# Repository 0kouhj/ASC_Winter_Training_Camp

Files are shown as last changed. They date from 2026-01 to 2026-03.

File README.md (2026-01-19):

# ASC_Winter_Training_Camp
## 项目成员
邓涵天 王泽源
## 仓库文件结构
- docs/ : 存放项目相关文档与图文资料
- Firmware/ : 放置单片机项目工程代码
- Hardware/ : 放置电路原理图及 PCB 源文件
- Mechanical/ : 放置各类机械结构 3D 模型文件 (STL/STEP)
## 项目代码结构 (Firmware)
- 工程基础文件 : 芯片启动文件及HAL库
- App/ : 应用层，用于存放控制算法（如 PID、滤波等）
- Bsp/ : 板级支持包，负责底层外设驱动（如 电机、传感器驱动）
- Config/ : 配置文件，存放系统参数设置与小车物理数据
## PCB丝印
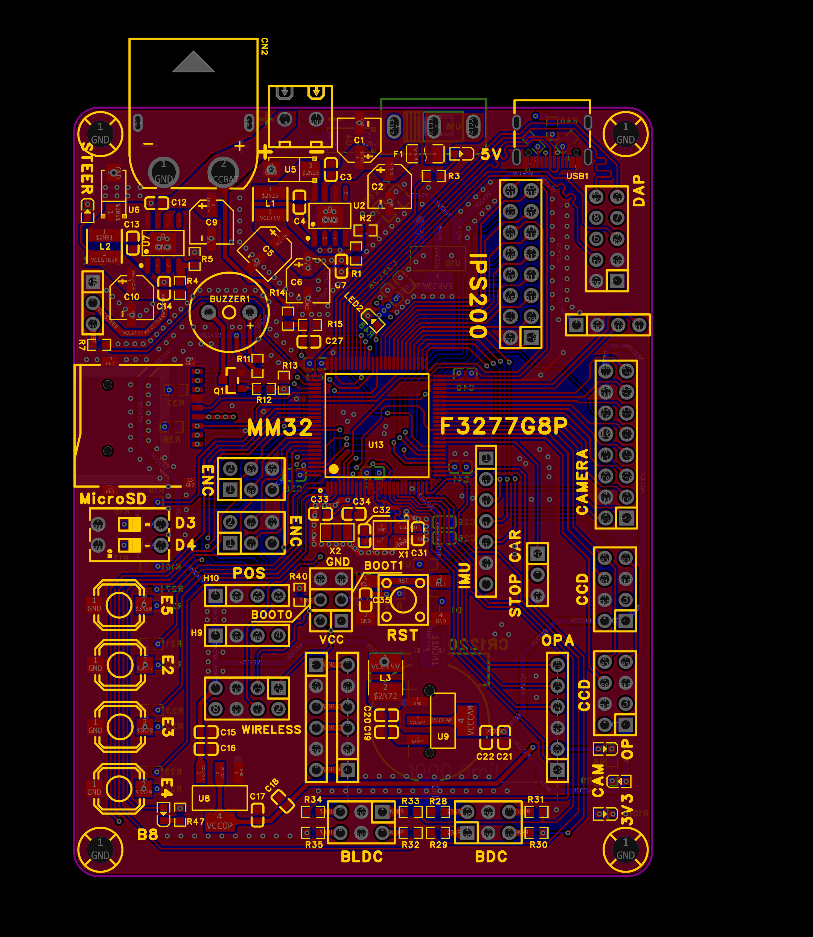
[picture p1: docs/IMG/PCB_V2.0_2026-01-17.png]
PCB_V2.0

## 硬件选型
1. 电机:MG513(GMR) 12V 1:30
2. 68mm硅胶轮胎
3. ICM42688姿态传感器

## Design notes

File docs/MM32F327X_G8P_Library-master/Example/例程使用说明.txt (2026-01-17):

例程的主要作用只是告诉大家如何使用各种库函数
因此例程内的库文件不一定是最新的，当通过库例程学习完之后
请使用 Seekfree_xxx_Opensource_Library 开源库进行开发。

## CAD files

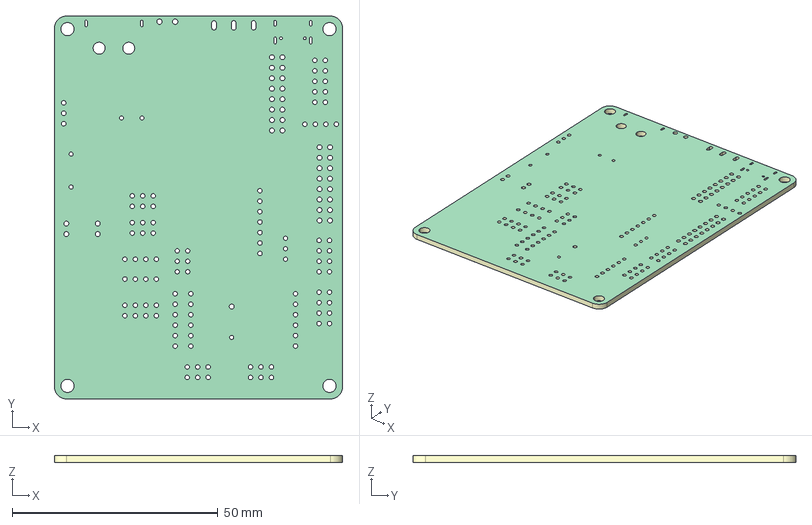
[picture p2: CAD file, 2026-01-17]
Mechanical/PCB_3D_V2.0_2026-01-17.step
70.0 x 93.0 x 1.59 mm
Board~gg4W
TopCopper~gg4W
BottomCopper~gg4W
TopFpcStiffener~gg4W
BottomFpcStiffener~gg4W

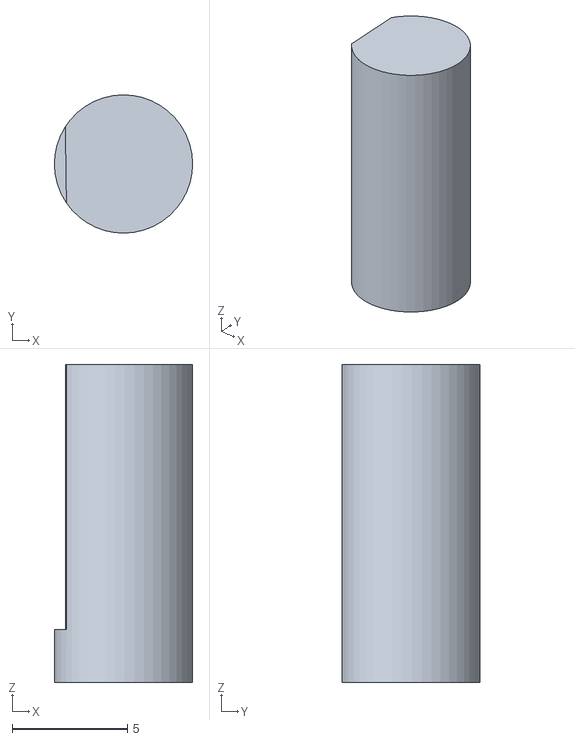
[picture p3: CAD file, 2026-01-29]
Mechanical/v2.0/STL打印文件/小车 - 电机轴.stp-1.STL
6.00 x 6.00 x 13.8

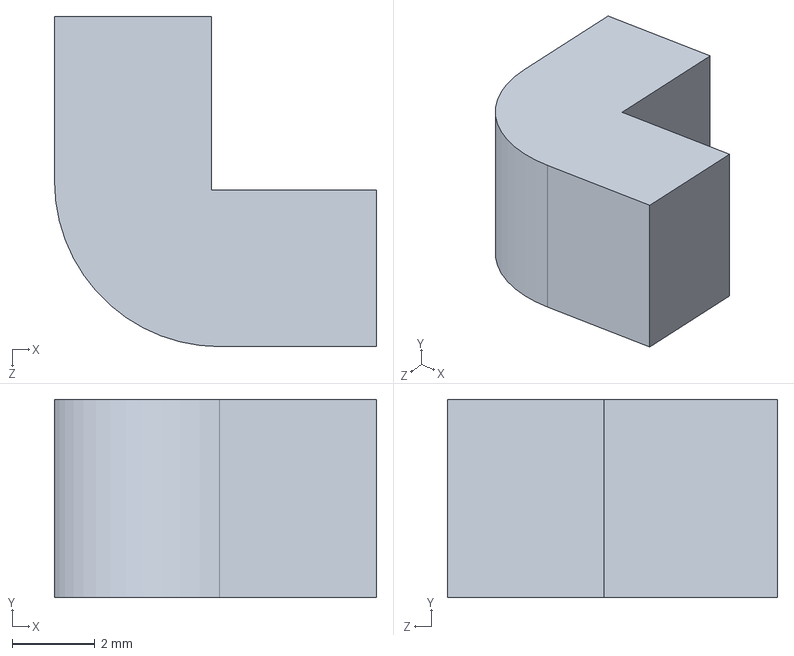
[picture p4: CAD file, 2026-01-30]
Mechanical/v2.0/插销.SLDPRT
7.80 x 4.80 x 8.00 mm

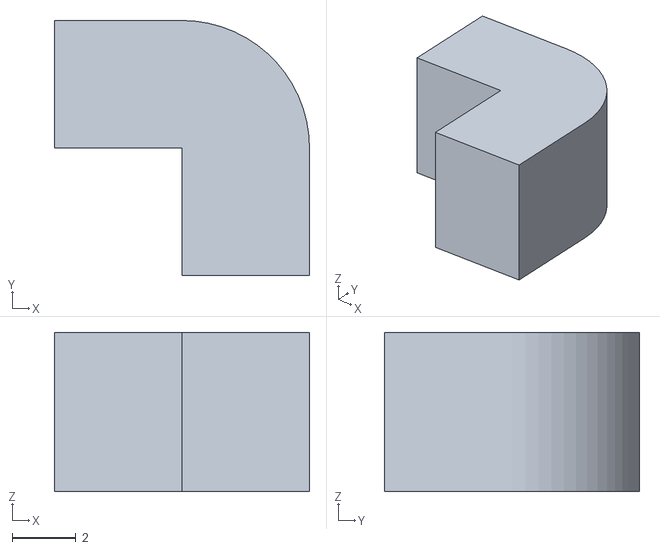
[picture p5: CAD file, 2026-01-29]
Mechanical/v2.0/STL打印文件/小车 - 插销-2.STL
8.00 x 8.00 x 5.00

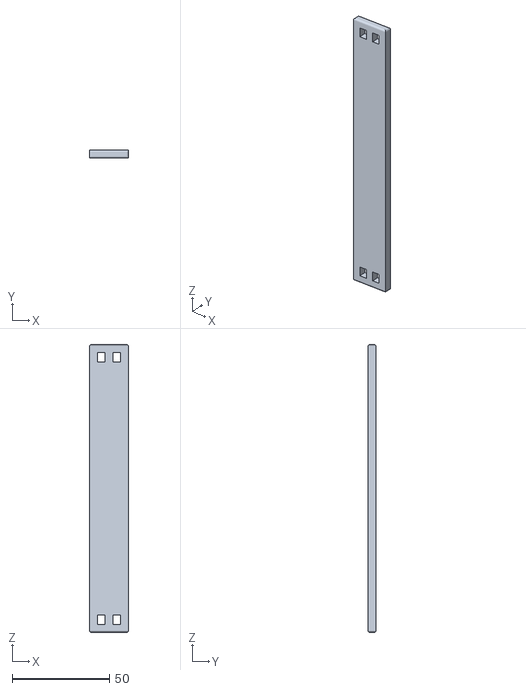
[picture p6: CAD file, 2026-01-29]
Mechanical/v2.0/STL打印文件/小车 - 电机下固定板-1.STL
20.0 x 4.00 x 148.0

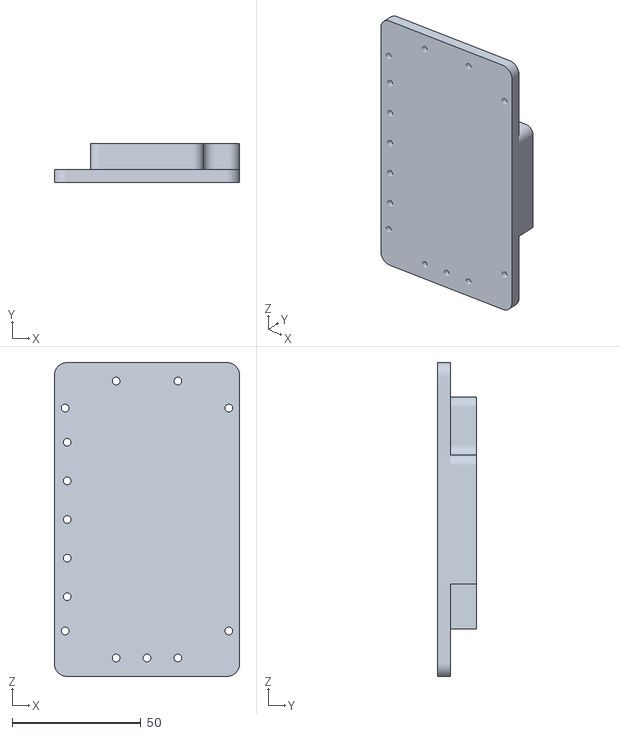
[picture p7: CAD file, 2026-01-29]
Mechanical/v2.0/STL打印文件/小车 - 底板-2.STL
72.0 x 15.0 x 122.0

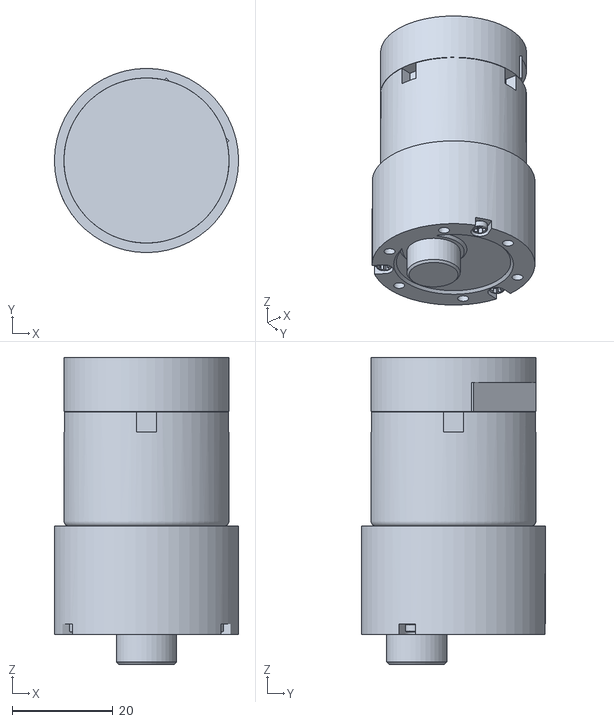
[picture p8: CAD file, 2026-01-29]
Mechanical/v2.0/STL打印文件/小车 - 电机后半部分.stp-2.STL
36.6 x 36.6 x 61.0

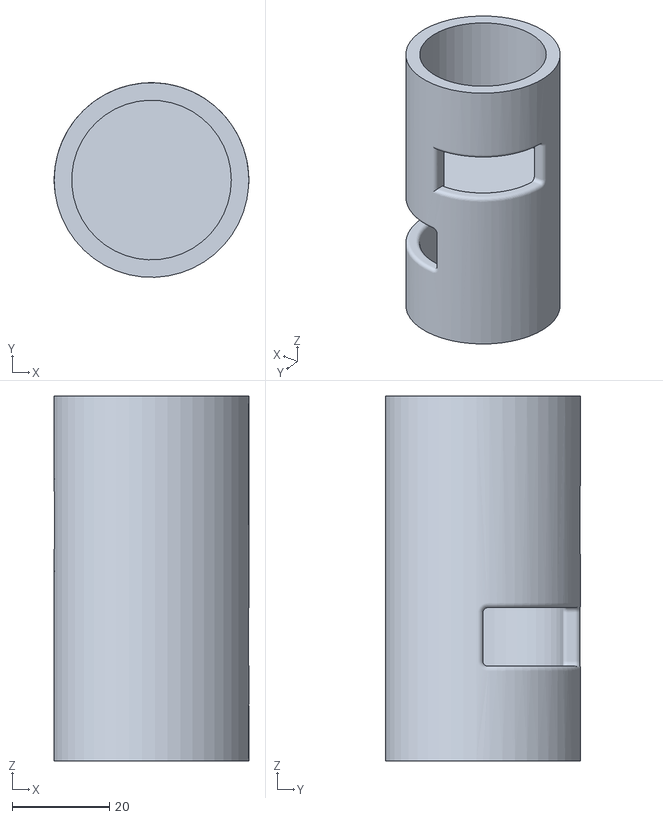
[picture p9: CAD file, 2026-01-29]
Mechanical/v2.0/STL打印文件/小车 - 电机套筒-1.STL
40.0 x 40.0 x 75.0

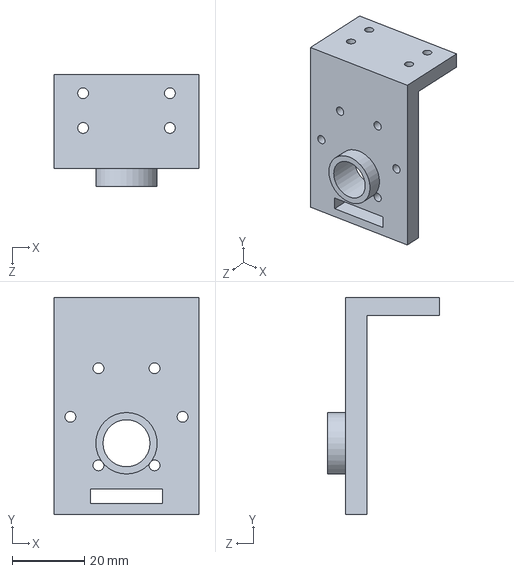
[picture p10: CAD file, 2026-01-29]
Mechanical/v2.0/电机固定件.SLDPRT
40.0 x 60.0 x 31.0 mm

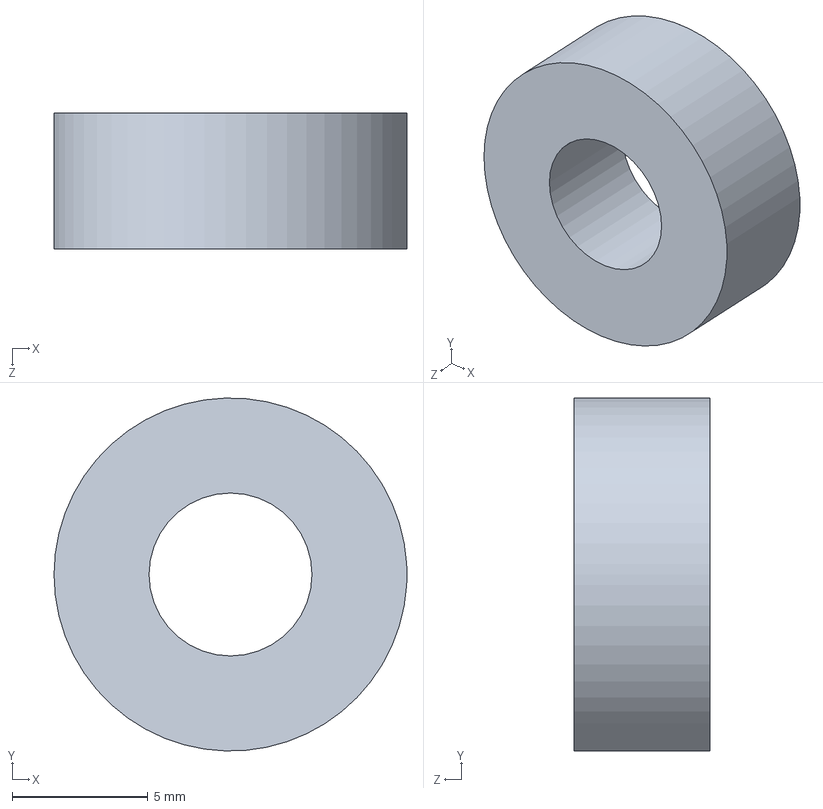
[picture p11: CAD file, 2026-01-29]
Mechanical/v2.0/轴承.SLDPRT
13.0 x 13.0 x 5.00 mm

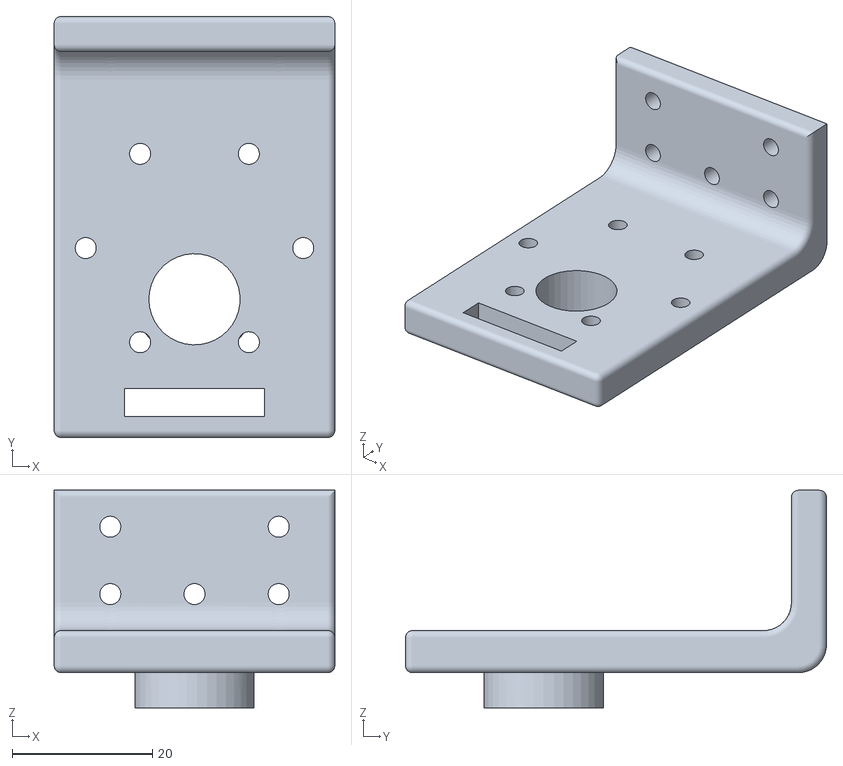
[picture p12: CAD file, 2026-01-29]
Mechanical/v2.0/STL打印文件/小车 - 电机固定件-2.STL
40.0 x 60.0 x 31.0

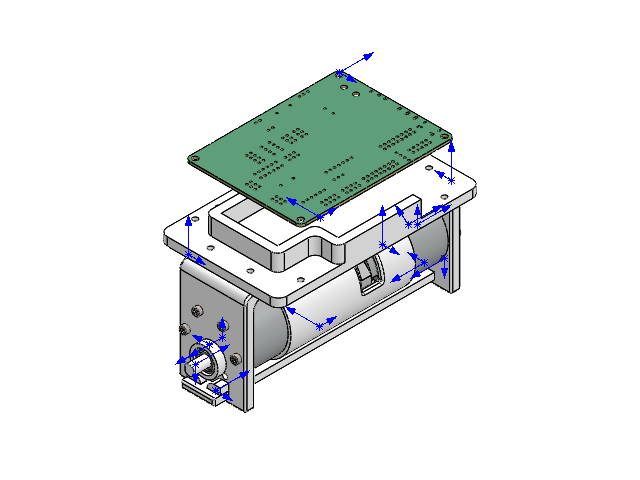
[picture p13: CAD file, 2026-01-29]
Mechanical/v2.0/小车.SLDASM
电机套筒
电机后半部分.stp x 2
电机轴.stp x 2
电机固定件 x 2
deep groove ball bearings gb x 2
hexagon socket head cap screws gb x 9
电机下固定板
插销 x 4
底板
Board~gg4W.step

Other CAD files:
Mechanical/v2.0/插销.gcode.3mf
Mechanical/v2.0/电机轴.stp.SLDPRT
Mechanical/v2.0/底座.SLDPRT
Mechanical/v2.0/11组v2.0小车.gcode.3mf
Mechanical/v2.0/STL打印文件/小车 - 电机轴.stp-2.STL
Mechanical/v2.0/STL打印文件/小车 - 插销-5.STL
Mechanical/v1.0/上底盘.SLDPRT
Mechanical/v1.0/下底盘.SLDPRT
Mechanical/v1.0/固定件-电机+下底盘.SLDPRT
Mechanical/v1.0/固定件-电机+电机.SLDPRT
Mechanical/v1.0/固定件.SLDPRT
Mechanical/v2.0/STL打印文件/小车 - 插销-1.3mf
Mechanical/v2.0/STL打印文件/小车 - 插销-1.STL
Mechanical/v2.0/STL打印文件/小车 - 插销-3.STL
Mechanical/v2.0/STL打印文件/小车 - 电机后半部分.stp-1.STL
Mechanical/v2.0/STL打印文件/小车 - 电机固定件-1.STL
Mechanical/v2.0/底板.SLDPRT
Mechanical/v2.0/插销.STL
Mechanical/v2.0/电机下固定板.SLDPRT
Mechanical/v2.0/电机后半部分.stp
Mechanical/v2.0/电机后半部分.stp.SLDPRT
Mechanical/v2.0/电机套筒.SLDPRT
Mechanical/v2.0/电机轴.stp

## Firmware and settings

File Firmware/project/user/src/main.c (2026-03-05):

/*********************************************************************************************************************
 * MM32F327X-G8P Opensourec Library 即（MM32F327X-G8P 开源库）是一个基于官方 SDK 接口的第三方开源库
 * Copyright (c) 2022 SEEKFREE 逐飞科技
 *
 * 本文件是 MM32F327X-G8P 开源库的一部分
 *
 * MM32F327X-G8P 开源库 是免费软件
 * 您可以根据自由软件基金会发布的 GPL（GNU General Public License，即 GNU通用公共许可证）的条款
 * 即 GPL 的第3版（即 GPL3.0）或（您选择的）任何后来的版本，重新发布和/或修改它
 *
 * 本开源库的发布是希望它能发挥作用，但并未对其作任何的保证
 * 甚至没有隐含的适销性或适合特定用途的保证
 * 更多细节请参见 GPL
 *
 * 您应该在收到本开源库的同时收到一份 GPL 的副本
 * 如果没有，请参阅<https://www.gnu.org/licenses/>
 *
 * 额外注明：
 * 本开源库使用 GPL3.0 开源许可证协议 以上许可申明为译文版本
 * 许可申明英文版在 libraries/doc 文件夹下的 GPL3_permission_statement.txt 文件中
 * 许可证副本在 libraries 文件夹下 即该文件夹下的 LICENSE 文件
 * 欢迎各位使用并传播本程序 但修改内容时必须保留逐飞科技的版权声明（即本声明）
 *
 * 文件名称          main
 * 公司名称          成都逐飞科技有限公司
 * 版本信息          查看 libraries/doc 文件夹内 version 文件 版本说明
 * 开发环境          IAR 8.32.4 or MDK 5.37
 * 适用平台          MM32F327X_G8P
 * 店铺链接          https://seekfree.taobao.com/
 *
 * 修改记录
 * 日期              作者                备注
 * 2022-08-10        Teternal            first version
 ********************************************************************************************************************/

#include "zf_common_headfile.h"
#include "zf_common_debug.h"
// 打开新的工程或者工程移动了位置务必执行以下操作
// 第一步 关闭上面所有打开的文件
// 第二步 project->clean  等待下方进度条走完

// 本例程是开源库移植用空工程

// **************************** 代码区域 ****************************
// *************************用户自定义包含****************************
#include "bsp_led.h"
#include "bsp_buzzer.h"
#include "bsp_oled.h"
#include "bsp_imu.h"
#include "bsp_motor.h"
#include "bsp_encoder.h"
#include "bsp_battery.h"
#include "bsp_bluetooth.h"

#include "kalman.h"

#include "Menu.h"
#include "Control.h"

#include "test.h"
#include "param_config.h"
#include "Simple_Timewheel.h"
// *************************用户自定义包含****************************

// 函数声明
static void OLED_Start(void);
// 函数声明

// DEBUG
char line_str[] = "*  DEBUG MODE ON  *\r\n";
// DEBUG

// Timewheel
extern volatile uint8_t tick_flag; // 时间轮滴答标志
extern volatile uint8_t tick_flag_2;
// Timewheel
int main(void)
{
    clock_init(SYSTEM_CLOCK_120M); // 初始化芯片时钟 工作频率为 120MHz
    debug_init();                  // 初始化默认 Debug UART

    // TIM 与 Encoder
    pit_ms_init(TIME_TIM, 1); // 使用TIM6进行按键扫描
    interrupt_set_priority(TIME_PRIORITY, 0);

    pit_ms_init(IMU_TIM, 1);
    interrupt_set_priority(IMU_PRIORITY, 1);
    // TIM 与 Encoder

    // 数据初始化
    Param_Init();
    // 数据初始化

    // 电机
    motor_init();
    encoder_init();
    // 电机

    // 此处编写用户代码 例如外设初始化代码等
    key_init(10);
    LED_Init();
    Buzzer_Init();
    battery_init();
    OLED_Init();
    Menu_Init();
    Attitude_Init();
    bluetooth_init();

    // 此处编写用户代码 例如外设初始化代码等

    // 自检
    LED_On(ALL);
    // Buzzer_On();
    OLED_Start();
    if (ICM42688_I2C_Init() != 0)
    {
        OLED_Clear();
        OLED_ShowString(0, 0, "IMU ERROR!", OLED_8X16);
        OLED_Update();
        system_delay_ms(1000);
    }
    else
    {
        OLED_Clear();
        OLED_ShowString(0, 0, "IMU OK!", OLED_8X16);
        OLED_Update();
        system_delay_ms(1000);
    }
    LED_Off(ALL);
    Buzzer_Off();
    // 自检

    OLED_Clear();

    add_task(1, All_Update);    // 每5ms更新所有控制相关任务
    add_task(30, Menu_Process); // 每30ms处理菜单
    // add_task(100, battery_update); // 每100ms更新电池电压
    add_task(30, key_scanner); // 每25ms按键扫描
    // add_task(10, Bluetooth_Command_Process); // 每10ms处理蓝牙命令

    sys_ready =1;

    while (1)
    {
        // Debug
        // OLED_Clear();
        // test_key();
        // Debug
        if (tick_flag)
        {
            time_wheel_run();
            tick_flag = 0;
        }
    }
}
// **************************** 代码区域 ****************************
static void OLED_Start(void)
{
    OLED_ShowString(0, 0, "---------------------", OLED_6X8);
    OLED_ShowString(0, 24, "---------------------", OLED_6X8);
    OLED_ShowString(0, 6, "->SYSTEM START<-", OLED_8X16);
    OLED_ShowString(0, 32, "Team Member:", OLED_8X16);
    OLED_ShowString(0, 48, "aaa", OLED_6X8);
    OLED_ShowString(0, 56, "bbb", OLED_6X8);
    OLED_ShowString(90, 32, "11", OLED_8X16);
    OLED_Update();
}

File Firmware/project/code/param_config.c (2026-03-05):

#include "param_config.h"
#include "Control.h"
// 实例化全局变量
SYSTEM_CONFIG_T Config;
SYSTEM_STATE_T State;
ICM42688_t Icm;
/**
 * @brief 初始化ICM42688的值
 * @note  开机时调用
 */
static void Icm42688_Init(void)
{
    // 原始数据清零
    Icm.accel_x_raw = 0;
    Icm.accel_y_raw = 0;
    Icm.accel_z_raw = 0;
    Icm.gyro_x_raw = 0;
    Icm.gyro_y_raw = 0;
    Icm.gyro_z_raw = 0;

    // 物理量清零
    Icm.accel_x_g = 0.0f;
    Icm.accel_y_g = 0.0f;
    Icm.accel_z_g = 0.0f;
    Icm.gyro_x_dps = 0.0f;
    Icm.gyro_y_dps = 0.0f;
    Icm.gyro_z_dps = 0.0f;
}

/**
 * @brief 实时状态初始化
 * @note  每次开机时调用，将所有状态清零
 */
static void State_Init(void)
{
    State.pitch = 0.0f;
    State.roll = 0.0f;
    State.yaw = 0.0f;
    State.gyro_x = 0.0f;
    State.gyro_y = 0.0f;
    State.motor_target_speed_left = 0;
    State.motor_target_speed_right = 0;
    State.motor_actual_speed_left = 0;
    State.motor_actual_speed_right = 0;
    State.is_stop = 0; // 开机默认锁定电机，保护安全
    State.run_stage = 0;
    State.loop_count = 0;
    State.menu_index = 0;
    State.battery_v = 0.0f;
    State.system_tick = 0;
}

/**
 * @brief 参数默认初始化
 * @note  当检测到Flash无数据时，加载这些默认值
 */
void Param_Init(void)
{
    State_Init();
    Icm42688_Init();

    // 1. 默认模式
    Config.boot.boot_mode = MODE_1;

    // 2. 电机环默认值
    Config.motor_l.Kp = 80.0f;
    Config.motor_l.Ki = 2.0f; // 适量积分消除稳态误差
    Config.motor_l.Kd = 0.5f;
    Config.motor_l.integral = 0.0f;
    Config.motor_l.i_max = 8000.0f; // 积分限幅，设为输出上限的一半
    Config.motor_l.err_last = 0.0f;
    Config.motor_l.out_max = MOTOR_MAX_PWM; // 必须设为 10000.0f

    Config.motor_r.Kp = 80.0f;
    Config.motor_r.Ki = 2.0f;
    Config.motor_r.Kd = 0.5f;
    Config.motor_r.integral = 0.0f;
    Config.motor_r.i_max = 8000.0f;
    Config.motor_r.err_last = 0.0f;
    Config.motor_r.out_max = MOTOR_MAX_PWM; // 必须设为 10000.0f

    // 3. 角速度环 (Gyro Loop: 平衡控制内环，抑制抖动)
    Config.gyro_loop.Kp = -1.05f; // 初始设为0，调参建议范围
    Config.gyro_loop.Ki = 0.0f; // 角速度环通常不需要积分
    Config.gyro_loop.Kd = 0.0f;
    Config.gyro_loop.integral = 0.0f;
    Config.gyro_loop.i_max = 9000.0f;
    Config.gyro_loop.err_last = 0.0f;
    Config.gyro_loop.out_max = MOTOR_MAX_PWM;

    // 4. 角度环 (Angle Loop: 平衡控制中环，维持直立)
    Config.angle_loop.Kp = 4.4f; // 初始设为0，调参建议范围: 200 - 600
    Config.angle_loop.Ki = 0.0f; // 角度环不建议使用积分，易导致低频震荡
    Config.angle_loop.Kd = 0.0f; // 角度环的D项通常作用于角速度
    Config.angle_loop.integral = 0.0f;
    Config.angle_loop.i_max = 9000.0f;
    Config.angle_loop.err_last = 0.0f;
    Config.angle_loop.out_max = 99000.0f; // 限制角度环输出的幅度

    // 5. 速度环 (Speed Loop: 平衡控制外环，维持静止/位移)
    Config.speed_loop.Kp = 0.0f; // 初始设为0，调参建议范围: 50 - 200
    Config.speed_loop.Ki = 0.0f; // 速度环必须有积分，用于消除静差（如坡道停车）
    Config.speed_loop.Kd = 0.0f;
    Config.speed_loop.integral = 0.0f;
    Config.speed_loop.i_max = 3000.0f;
    Config.speed_loop.err_last = 0.0f;
    Config.speed_loop.out_max = 20.0f; // 速度环输出的是目标角度，不宜过大

    // 6. 转向环 (Yaw Loop)
    Config.yaw_loop.Kp = 0.0f;
    Config.yaw_loop.Ki = 0.0f;
    Config.yaw_loop.Kd = 0.0f;
    Config.yaw_loop.integral = 0.0f;
    Config.yaw_loop.i_max = 1000.0f;
    Config.yaw_loop.err_last = 0.0f;
    Config.yaw_loop.out_max = MOTOR_MAX_PWM;

    // 7. 运动参数
    Config.path.move_speed = 50;
    Config.path.target_dist_AB = 1000.0f;

    Config.checksum = 0x12345678;
}

volatile uint8_t sys_ready;
volatile uint16_t fuck_imu;

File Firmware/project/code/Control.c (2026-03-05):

#include "Control.h"
#include "zf_common_headfile.h"
#include "bsp_imu.h"
#include "bsp_encoder.h"
#include "bsp_motor.h"
#include "math.h"

/**
 * @brief 简化后的速度反馈（直接返回每毫秒脉冲数）
 */
float Motion_Get_Speed_L(int32_t pulse_count)
{
    static float filtered_pulses_l = 0.0f; // 必须使用独立的静态变量
    const float alpha = 0.3f;              // 1ms下兼顾响应与平滑

    filtered_pulses_l = alpha * (float)pulse_count + (1.0f - alpha) * filtered_pulses_l;
    if (fabsf(filtered_pulses_l) < 1.0f)
        filtered_pulses_l = 0.0f;
    return -filtered_pulses_l;
}

float Motion_Get_Speed_R(int32_t pulse_count)
{
    static float filtered_pulses_r = 0.0f; // 必须使用独立的静态变量
    const float alpha = 0.3f;

    filtered_pulses_r = alpha * (float)pulse_count + (1.0f - alpha) * filtered_pulses_r;

    if (fabsf(filtered_pulses_r) < 1.0f)
        filtered_pulses_r = 0.0f;

    return -filtered_pulses_r;
}

/**
 * @brief Motor PID 计算函数
 * @param pid  PID 结构体指针
 * @param error 当前误差 (目标值 - 实际值)
 * @return float 计算得出的 PWM 或 修正量
 */
float PID_Compute_Motor(STRUCT_PID *pid, float target, float actual)
{
    float error = target - actual;
    float current_kp = pid->Kp;

    // --- 分段 Kp 逻辑：未达到目标速度 2/3 时，Kp 翻倍 ---
    // 使用 fabsf 保证正反转逻辑一致
    if (fabsf(actual) < fabsf(target) * 0.8f)
    {
        current_kp = pid->Kp * 2.5f; // 起步增益，可根据实际效果在 1.5~2.5 之间调整
    }

    // 1. P 输出
    float p_out = current_kp * error;

    // 2. I 输出 (累加误差)
    pid->integral += error;
    if (pid->integral > pid->i_max)
        pid->integral = pid->i_max;
    if (pid->integral < -pid->i_max)
        pid->integral = -pid->i_max;

    float i_out = pid->Ki * pid->integral;

    // 3. D 输出 (误差变化率)
    float d_out = pid->Kd * (error - pid->err_last);
    pid->err_last = error;

    // 4. 合并输出并进行最终限幅
    float out = p_out + i_out + d_out;

    if (out > pid->out_max)
        out = pid->out_max;
    if (out < -pid->out_max)
        out = -pid->out_max;

    return out;
}
/**
 * @brief  位置式 PID 计算函数
 * @param  pid:    指向 STRUCT_PID 结构体的指针
 * @param  target: 目标值
 * @param  real:   当前实际测量值
 * @return float:  PID 计算后的输出值
 */
float pid_control(STRUCT_PID *pid, float target, float real)
{
    float err = 0;  // 当前偏差
    float diff = 0; // 微分项
    float out = 0;  // 临时输出结果

    // 1. 计算当前偏差 (Error)
    err = target - real;

    // 2. 积分项累加 (Integral)
    pid->integral += err;

    // 3. 积分抗饱和 (Anti-windup)
    // 根据结构体定义中的 i_max 进行限幅
    if (pid->integral > pid->i_max)
        pid->integral = pid->i_max;
    if (pid->integral < -pid->i_max)
        pid->integral = -pid->i_max;

    // 4. 微分项计算 (Derivative)
    // 使用当前偏差减去结构体中存储的 err_last
    diff = err - pid->err_last;

    // 5. PID 公式拟合
    out = (pid->Kp * err) + (pid->Ki * pid->integral) + (pid->Kd * diff);

    // 6. 输出限幅
    if (out > pid->out_max)
        out = pid->out_max;
    if (out < -pid->out_max)
        out = -pid->out_max;

    // 7. 更新历史偏差，供下次微分计算使用
    pid->err_last = err;

    return out;
}

/**
 * @brief  平衡小车 1ms 核心控制函数
 * @param  target_speed: 期望速度
 * @param  target_yaw:   期望转向角
 */
void Control_Loop_1ms(float target_speed, float target_yaw_rate)
{
    static uint8_t speed_count = 0;
    static uint8_t speed_count_1 = 0;
    static float speed_target_angle = 0.0f; // 速度环输出：期望倾角

    float target_gyro_y = 0.0f;

        // 0. 检查停机状态
        if (State.is_stop)
    {
        // 停机时清空所有积分项，防止复位瞬间产生巨大脉冲
        Config.speed_loop.integral = 0;
        Config.angle_loop.integral = 0;
        Config.gyro_loop.integral = 0;
        Config.motor_l.integral = 0;
        Config.motor_r.integral = 0;

        // 输出清零
        State.motor_target_speed_left = 0;
        State.motor_target_speed_right = 0;
        return;
    }

    // --- 第一层：速度环 (Speed Loop) ---
    // 20ms运行一次。速度环必须慢，否则会干扰平衡环的快速响应
    speed_count++;
    if (speed_count >= 20)
    {
        float current_speed = (State.motor_actual_speed_left + State.motor_actual_speed_right) / 2.0f;

        // 速度环输出给角度环：为了往前走，车必须先往前倾
        // 注意：此处输出通常需要限制在安全角度内（如 -15° 到 15°）
        speed_target_angle = pid_control(&Config.speed_loop, target_speed, current_speed);
        speed_count = 0;
    }

    // --- 第二层：角度环 (Angle Loop) ---
    // 5ms运行一次。输入：期望倾角，反馈：当前加速度计计算出的 Pitch
    speed_count_1++;
    // 角度环输出 = 目标角速度
    if (speed_count_1 >=5)
    {
        speed_count_1 = 0;
        target_gyro_y = pid_control(&Config.angle_loop, speed_target_angle, State.pitch);
    }


    // --- 第三层：角速度环 (Gyro Loop) ---
    // 1ms运行一次。这是最关键的内环，直接决定车的稳定性
    // 输入：角度环给出的目标角速度，反馈：陀螺仪实时角速度 (State.gyro_y)
    float balance_output = pid_control(&Config.gyro_loop, target_gyro_y, State.gyro_y);

    // --- 转向环 (Yaw Loop) ---
    // 转向通常作为差分量叠加。输入：目标转向速度，反馈：陀螺仪 Z 轴角速度
    float yaw_output = 0; // pid_control(&Config.yaw_loop, target_yaw_rate, State.gyro_z);

    // --- 最终输出叠加与映射 ---
    // 1. 叠加平衡量与转向差分量
    float out_l = balance_output + yaw_output;
    float out_r = balance_output - yaw_output;

    // 2. 这里的输出通常直接作为底层“电机电流环”或“电机速度环”的输入
    // 如果没有底层环，则直接映射为 PWM 占空比。
    // 注意：需根据实际电机性能进行限幅（例如 PWM 最大值为 10000）
    State.motor_target_speed_left = out_l;
    State.motor_target_speed_right = out_r;
}

void All_Update(void)
{
    static uint8_t speed_cnt = 0;

    // 1ms 执行一次 IMU 更新

    // 2. 输出姿态传感器数据
    //char str[128];
    // sprintf(str, "%f,%f,%f,%f\n", State.pitch, State.roll, State.yaw,State.gyro_x);
    // uart_write_string(DEBUG_UART_INDEX, str);

    // 3. 输出电机速度控制逻辑
    //sprintf(str, "%f,%f,%f,%f\n", State.motor_target_speed_left, State.motor_target_speed_right, State.motor_actual_speed_left, State.motor_actual_speed_right);
    //uart_write_string(DEBUG_UART_INDEX, str);
}

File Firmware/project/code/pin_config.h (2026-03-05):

#ifndef PIN_CONFIG_H
#define PIN_CONFIG_H

// 驱动定义
#define BATTERY_ADC (ADC2_CH14_C4)

#define BLUETOOTH_TX (UART6_TX_C6)
#define BLUETOOTH_RX (UART6_RX_C7)
#define BLUETOOTH_BAUD (9600)
#define BLUETOOTH_UART_INDEX (UART_6)
#define BLUETOOTH_UART_PRIORITY (UART6_IRQn)

#define LED_1 (H2)
#define LED_2 (B8)

#define DOUBLE_KEY_1 (D3)
#define DOUBLE_KEY_2 (D4)

#define BUZZER (D7)

#define IMU_CS (B12)
#define IMU_SCLK (B13)
#define IMU_MOSI (B14)
#define IMU_MISO (B15)

#define OLED_SCL (A7)
#define OLED_SDA (A5)

// 电机
#define PWM_R (TIM5_PWM_CH2_A1)
#define PWM_L (TIM5_PWM_CH1_A0)

#define ENCODER_RIGHT_A (TIM3_ENCODER_CH1_B4)
#define ENCODER_RIGHT_B (TIM3_ENCODER_CH2_B5)

#define ENCODER_LEFT_A (TIM4_ENCODER_CH1_B6)
#define ENCODER_LEFT_B (TIM4_ENCODER_CH2_B7)

#define Motor_L_DIR (D5)

#define Motor_R_DIR (D6)

// 软件定义

#define TIME_TIM (TIM6_PIT)
#define TIME_PRIORITY (TIM6_IRQn)

#define IMU_TIM (TIM7_PIT)
#define IMU_PRIORITY (TIM7_IRQn)

#endif

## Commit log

2026-01-17 添加PCB的3D文件,一个包含元器件与丝印,一个只有PCB文件
    [PCB_3D_V2.0_2026-01-17.step]
2026-01-17 1.完善仓库文件结构\n2.添加MM32文档\n3.添加EDA工程文件\n4.添加丝印PNG
    [MM32F327xG8P_CoreBoard.PcbLib, MM32F327xG8P_CoreBoard.SchLib, PCB_3D_V2.0_2026-01-17.step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]
2026-01-19 添加直流电机3D模型
    [直流电机_MG513P30（P20）-12V（GMR）.stp]
2026-01-19 添加空项目文件,能够顺利使用vscode编译
2026-01-19 完善了项目的文件系统,区分为App,Bsp,Config三个文件夹,分别用于算法,驱动与设置项
2026-01-19 更改readme
2026-01-19 在Readme中添加硬件选型
2026-01-23 写好了按钮驱动与链表菜单
2026-01-23 完善了菜单系统的结构,写好了param_config中存储或不存储到flash中的变量以及对应的初始化程序
2026-01-23 增加其余车模配件
    [上底盘.SLDPRT, 下底盘.SLDPRT, 固定件.SLDPRT]
2026-01-24 修改了车模结构
2026-01-24 写好了I2c版本的IMU驱动,.添加kalman滤波函数
2026-01-24 完善IMU解算,使用kalman滤波
2026-01-24 再次更新了车模结构，增加稳定性降低振动
    [下底盘.SLDPRT, 固定件-电机+下底盘.SLDPRT, 固定件-电机+电机.SLDPRT]
2026-01-24 完善了电机驱动代码,发现一个tb6612无法驱动两个电机,要两个才行QAQ
2026-01-24 写好的电池电压检测函数,在Info菜单中显示
2026-01-24 创建flash文件
2026-01-25 写好了编码器驱动
2026-01-25 更改车模结构
    [上底盘.SLDPRT, 下底盘.SLDPRT, 固定件-电机+下底盘.SLDPRT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]
2026-01-25 进行时间轮改动前的提交
2026-01-25 增加菜单编辑模式，实现菜单交互更改PID参数
2026-01-25 增加菜单交互模式
2026-01-25 菜单交互补丁
2026-01-26 添加时间轮改动
2026-01-26 完善修改代码格式,删除多余代码
2026-01-26 测速电机死区,将Actual_Speed转化为实际速度(m/s)
2026-01-26 写好了基础蓝牙驱动,做到了发送接收的基本功能
2026-01-26 删除发送的环形缓冲(感觉没必要,不如直接改标志位在OLED显示)
2026-01-26 添加命令解析函数,使用[]作为包头与包尾,更改isr内容,使用命令解析状态机
2026-01-26 完美的底层
2026-01-26 三环PID架构
2026-01-26 回退代码至“完美的底层”版本
2026-01-29 添加结构2.0文件与直插电机驱动PCB文件
    [11组v2.0小车.gcode.3mf, 上底盘.SLDPRT, 下底盘.SLDPRT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]
2026-01-30 更改了插销件结构
    [插销.SLDPRT, 插销.STL, 插销.gcode.3mf]
2026-01-30 添加ICM42688硬件低通滤波
2026-01-30 更改变量位置使其更加规范,在PID结构体中添加限幅
2026-01-30 完善所有PID控制程序,添加初始化限幅,未调参
2026-01-31 勉强能用的电机PID
2026-01-31 还不错的电机PID控制
2026-02-01 改变频率后电机还不错的一版
2026-03-01 电机0~65,右电机无力
2026-03-04 电机非PID
2026-03-05 平衡车架构
